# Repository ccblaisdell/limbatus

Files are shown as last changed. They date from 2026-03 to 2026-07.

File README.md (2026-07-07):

# limbatus

A 34-key wireless monoblock ergonomic keyboard derived from Dimetrodon.

## Current status
- Ships as a **34-key** layout (`thumb_keys_per_side: 2` in `ergogen/config.yaml`).
- Matrix is organized as a XIAO BLE-compatible logical `6 x 6` scan.
- `NFC1` is reserved for matrix use and must be configured as GPIO in firmware.

> The config also retains an optional **36-key** mode (`thumb_keys_per_side: 3`,
> which adds a third thumb key per side) as build infrastructure. The keyboard is
> designed, documented, and built as a 34-key; the 36-key path is kept working but
> not advertised.

## Latest PCB Images
- Top view: https://ccblaisdell.github.io/limbatus/limbatus-top.png
- Bottom view: https://ccblaisdell.github.io/limbatus/limbatus-bottom.png

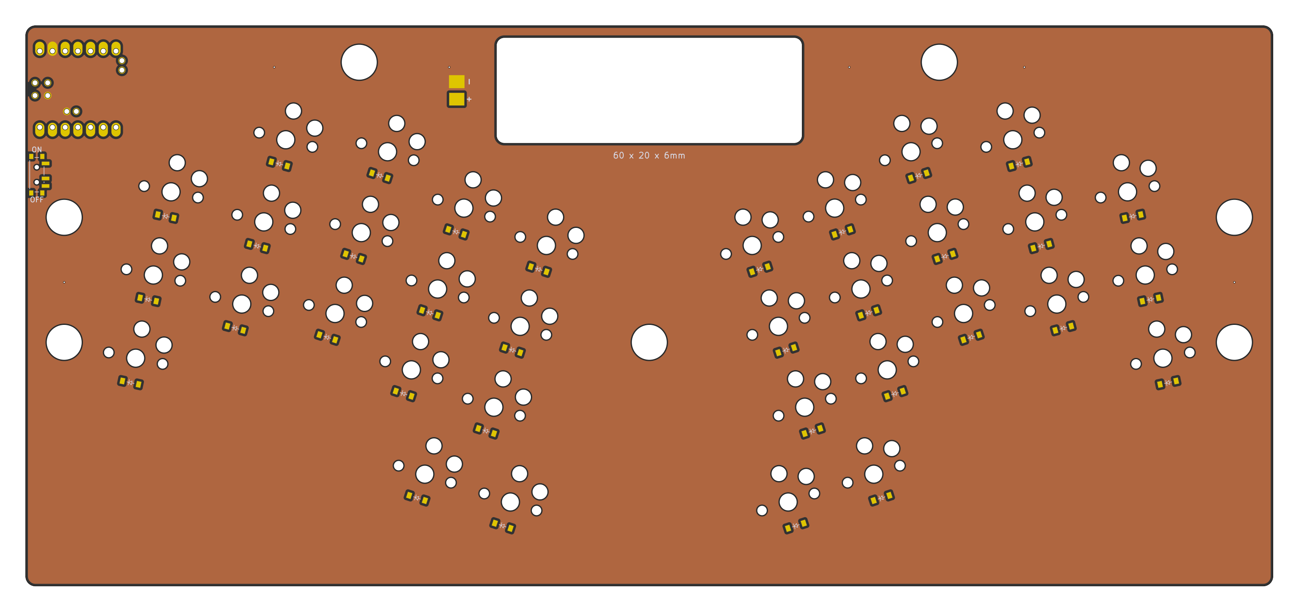
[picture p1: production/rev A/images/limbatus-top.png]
Limbatus top view

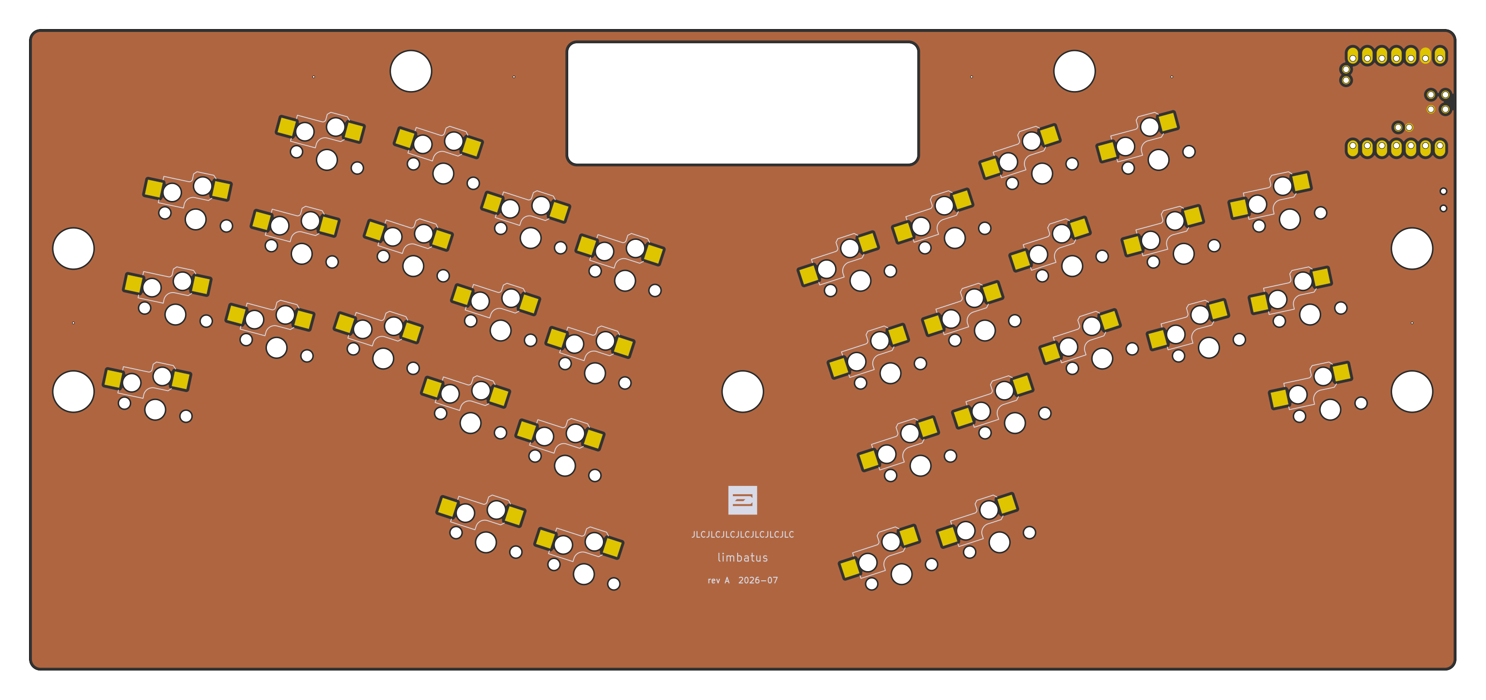
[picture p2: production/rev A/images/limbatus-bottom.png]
Limbatus bottom view


## Build
1. Install dependencies:
   - `npm install`
2. Generate artifacts:
   - `make build`

For hand-assembly (soldering and case), see [`BUILD.md`](BUILD.md). Parts list is in [`BOM.md`](BOM.md).

## Firmware
Runs [ZMK](https://zmk.dev) as a single (non-split) XIAO BLE image. The config,
keymaps, pin map, and build/flash notes live in [`config/`](config/README.md);
CI builds the `limbatus` (34-key) and `limbatus_36` (36-key) shields and uploads
`.uf2` artifacts.

Default 34-key keymap (rendered by [keymap-drawer](https://github.com/caksoylar/keymap-drawer)):

limbatus keymap

## Verify Ergogen Changes
Run this whenever you change `ergogen/config.yaml`.

1. Confirm current thumb mode value:
   - `rg -n "thumb_keys_per_side" ergogen/config.yaml`
2. Build with current mode:
   - `make build`
3. Verify generated artifacts exist:
   - `ls outlines`
   - `ls pcbs`
4. Check what changed:
   - `git status --short`
5. Validate both key-count modes before merging layout changes:
   - 34-key mode: set `thumb_keys_per_side: 2` and set both reachy `skip` fields to `true`, then run `make build`
   - 36-key mode: set `thumb_keys_per_side: 3` and set both reachy `skip` fields to `false`, then run `make build`
6. In KiCad, open the generated board and confirm:
   - no missing footprints
   - expected key count (34 or 36)
   - MCU footprint placement still valid
   - no obvious overlap/regression in thumb cluster or center bridge

## Keyboard References
- https://github.com/ceoloide/corney-island for its GitHub Actions and workflows.
- https://github.com/ccblaisdell/dimetrodon for your previous keyboard iteration.

## Notes
- Target MCU is XIAO BLE nRF52840.
- Matrix pin map target: `P0..P5` for columns, `P6..P10` plus `NFC1` for rows.
- Includes a dedicated power switch footprint.
- No JST footprint; battery uses two direct-solder SMD pads (`local/battery_pads_solder`).
- No external reset switch footprint; rely on the onboard XIAO reset button.
- The current code-generated case approach is documented in `case/README.md` and is intended to use Ergogen DXFs plus an OpenSCAD/FreeCAD export flow.

## TODO
- Add 3d models for parts where possible
- Implement the code-generated case plan in `case/README.md`
- Design a second case with embedded apple magic trackpad

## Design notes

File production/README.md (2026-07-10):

# Production artifacts

This directory holds **production bundles**: frozen snapshots of the exact
fabrication artifacts for a specific board revision — the gerbers you actually
order, together with the PCB and outlines they were generated from.

Everything else generated by Ergogen (`outlines/`, `pcbs/`) and by KiBot
(root `gerbers/`) is a **live build product** and is intentionally *not* committed
(see `.gitignore`). `ergogen/config.yaml` is the single source of truth; run
`make build` (or download the CI build artifacts) to regenerate the current
design at any time.

## Layout

```
production/
  rev <version>/                 # e.g. 2026-08-01-jlcpcb
    gerbers/
      limbatus/               # base-board gerbers
      limbatus.zip            # the zip actually uploaded to the fab
      limbatus_autorouted/    # autorouted-board gerbers (if used)
      limbatus_autorouted.zip
    limbatus.kicad_pcb        # the exact PCB the gerbers came from
    outlines/                 # matching board/case outlines
    BOM.csv                   # optional: BOM as ordered
    SOURCE.md                 # provenance: source commit, date, fab, order id
```

A bundle is **immutable** once committed. It is guaranteed internally consistent
(gerbers ⇄ PCB ⇄ outlines all from one build), which is the property root-level
live outputs cannot promise as the design evolves.

## Cutting a new production bundle

Bundles are created and committed **by hand** — nothing in CI writes here.
When you are ready to place an order:

1. Regenerate from the commit you intend to fab: `make build`, then run the
   KiBot/autoroute steps to produce `gerbers/` (or pull them from the `Build`
   workflow's `kibot-default` artifact for that commit).
2. Copy the artifacts into `production/<order-id>/`:
   - `gerbers/`            → `production/<order-id>/gerbers/`
   - `pcbs/limbatus.kicad_pcb` → `production/<order-id>/limbatus.kicad_pcb`
   - `outlines/`          → `production/<order-id>/outlines/`
3. Write `production/<order-id>/SOURCE.md` recording the source commit, date,
   fab, and order id (copy an existing bundle's `SOURCE.md` as a template).
4. Commit the bundle and tag it: `git tag fab-<order-id> && git push --tags`.

Because `outlines/`, `pcbs/`, and root `gerbers/` are gitignored, use
`git add -f production/<order-id>` — the `production/` path itself is not
ignored, so a normal `git add production/<order-id>` works too.

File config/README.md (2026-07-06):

# limbatus ZMK firmware

ZMK config for **limbatus**, a monoblock (unibody, non-split) wireless keyboard
built on a single Seeed **XIAO BLE nRF52840** driving a logical **6×6 diode
matrix**. This is the shipping **34-key** layout.

Because limbatus is unibody, each build is one firmware image (one
`board + shield` pair) — not the `_left` / `_right` split pair you'd see on a
Dimetrodon-style board. Two shields share the same board and matrix:
`limbatus` (34-key, shipping default) and `limbatus_36` (36-key, retained).

## Layout

```
build.yaml                                   GitHub Actions build matrix (both shields)
config/
  west.yml                                   ZMK + urob/zmk-helpers, both pinned
  limbatus.keymap                            34-key keymap (QWERTY / NAV / SYM / FUN)
  limbatus_36.keymap                         36-key keymap (adds the 3rd thumb/side)
  limbatus.conf                              user Kconfig (battery, sleep, logging)
  boards/shields/limbatus/
    limbatus.dtsi                            shared kscan matrix (both shields)
    limbatus.overlay                         34-key transform + chosen
    limbatus_36.overlay                      36-key transform + chosen
    limbatus.conf / limbatus_36.conf         shield requirement (NFC pins as GPIO)
    limbatus.yml / limbatus_36.yml           shield metadata
    Kconfig.shield / Kconfig.defconfig       shield selection + names
keymap_drawer.config.yaml                    keymap-drawer styling
keymap-drawer/
  limbatus.json / limbatus_36.json           physical layouts for the drawer (source)
  *.svg                                       generated keymap images (committed by CI)
.github/workflows/zmk-build.yml              firmware CI (pinned reusable workflow)
.github/workflows/draw-keymaps.yml           keymap image CI (keymap-drawer)
```

## Matrix ↔ pin mapping

The single source of truth for wiring is `ergogen/config.yaml`
(`pcbs.limbatus.footprints.xiao_ble`). This firmware mirrors it:

| Matrix | XIAO pin | ZMK reference | nRF pin |
| --- | --- | --- | --- |
| C0 | D0  | `&xiao_d 0`  | P0.02 |
| C1 | D1  | `&xiao_d 1`  | P0.03 |
| C2 | D2  | `&xiao_d 2`  | P0.28 |
| C3 | D3  | `&xiao_d 3`  | P0.29 |
| C4 | D4  | `&xiao_d 4`  | P0.04 |
| C5 | D5  | `&xiao_d 5`  | P0.05 |
| R0 | D6  | `&xiao_d 6`  | P1.11 |
| R1 | D7  | `&xiao_d 7`  | P1.12 |
| R2 | D8  | `&xiao_d 8`  | P1.13 |
| R3 | D9  | `&xiao_d 9`  | P1.14 |
| R4 | D10 | `&xiao_d 10` | P1.15 |
| R5 | NFC1 | `&gpio0 9`  | P0.09 |

Diodes run switch→row with the anode on the column side, so
`diode-direction = "col2row"`: columns are strobed outputs, rows are sampled
inputs (pulled down).

**NFC pin:** R5 lives on P0.09, an NFC antenna pin by default.
`boards/shields/limbatus/limbatus.conf` sets `CONFIG_NFCT_PINS_AS_GPIOS=y` so
P0.09/P0.10 become plain GPIO. This is written into UICR on first flash; if the
sixth row is dead, confirm this landed. (Matches the CLAUDE.md decision: "disable
NFC and use NFC1 as GPIO for the sixth matrix row.")

## Building

CI (`.github/workflows/zmk-build.yml`) builds `xiao_ble//zmk` with both the
`limbatus` and `limbatus_36` shields on every push that touches `config/**` or
`build.yaml`, and uploads a `firmware` artifact containing `limbatus.uf2` /
`limbatus_36.uf2`. Flash the one you built by double-tapping reset (via the case
tab) to enter the UF2 bootloader and dropping the `.uf2` onto the mass-storage
volume.

The board target is `xiao_ble//zmk` — the `//zmk` selects ZMK's board variant
(the SoC is omitted since nRF52840 is the only one). Plain `xiao_ble` builds the
bare Zephyr board and CI rejects it as "Missing ZMK Compat".

Local build (34-key; use `-DSHIELD=limbatus_36` for the 36-key build):

```sh
west build -s zmk/app -b 'xiao_ble//zmk' -- -DSHIELD=limbatus -DZMK_CONFIG=$(pwd)/config
```

## Keymap images

`.github/workflows/draw-keymaps.yml` renders each keymap with
[keymap-drawer](https://github.com/caksoylar/keymap-drawer) on every keymap
change and commits the SVGs into `keymap-drawer/`. limbatus is an unknown board
to keymap-drawer, so we ship the physical layout as QMK-style `info.json` files
(`keymap-drawer/limbatus.json`, `limbatus_36.json`) — a split 3×5 with 2 (or 3)
thumbs per side — which the workflow auto-detects via `json_path`.

<!-- These render once the draw-keymaps workflow has run and committed the SVGs. -->
### 34-key (`limbatus`)
limbatus keymap

### 36-key (`limbatus_36`)
limbatus_36 keymap

## Versions

ZMK and urob/zmk-helpers are pinned in `config/west.yml`; the reusable build
workflow in `.github/workflows/zmk-build.yml` is pinned to the **same** ZMK
commit. Bump them together. ZMK is currently tracking a `main` commit (there is
no release tag yet that ships the `xiao_ble` board id used here); if CI breaks
after a helper bump, re-pin to a known-good pair.

## 34-key vs 36-key

Both modes share `limbatus.dtsi` (the 6×6 kscan is identical); only the
matrix-transform and keymap differ. The 36-key build adds the third "reachy"
thumb per side at the otherwise-unused intersections **C5,R2** (left) and
**C5,R5** (right), so a 34-key board simply never scans them. Transform thumb
rows (verified against generated PCB geometry, outer→inner):

| | left thumbs | right thumbs |
| --- | --- | --- |
| 34-key | tucky `RC(0,5)`, middle `RC(1,5)` | middle `RC(4,5)`, tucky `RC(3,5)` |
| 36-key | tucky `RC(0,5)`, middle `RC(1,5)`, reachy `RC(2,5)` | reachy `RC(5,5)`, middle `RC(4,5)`, tucky `RC(3,5)` |

The 34-key `limbatus` is the advertised/shipping default; `limbatus_36` is kept
building so the option doesn't rot (mirrors the ergogen `thumb_keys_per_side`
toggle). Match the firmware you flash to the number of thumb switches you built.

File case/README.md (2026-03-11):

# Parametric Wedge Case Generator

## Summary
Build a code-generated case pipeline that uses Ergogen as the geometry source of truth and OpenSCAD as the solid-modeling layer. The repo will generate:

- board and cavity outlines as DXF from `ergogen/config.yaml`
- a two-part printable case as STL
- STEP exports via a scripted FreeCAD conversion step

The case will be a rectangular top view with a wedge side profile, split into a `top shell` and `bottom tray`. The top shell will act as a switch plate with top openings for switches/keycaps. The interior will include cavities for the XIAO, battery, and power switch, with rear openings for USB and switch access. The bottom tray will include underside cutouts for the XIAO and hotswap hardware.

## Review Notes
- Keep this aligned with repo policy: there is a dedicated power switch footprint, there is no JST battery connector, and reset access is via the onboard XIAO button unless the PCB later proves that inadequate.
- Ergogen must remain the source of truth for 2D geometry. Case inputs should be derived DXFs, not hand-maintained sketches.
- The plan needs to support both 34-key and 36-key modes. Any case-driving outlines tied to switch pattern or exterior perimeter need validation in both modes.
- The current plan is viable, but implementation should start with a minimal pipeline that proves geometry export and shell generation before adding STEP conversion and more detailed internal features.

## Implementation Changes
### Geometry source
- Extend `ergogen/config.yaml` with named case-driving outlines for:
  - outer board/case perimeter
  - switch opening pattern / plate geometry
  - diode clearance envelope if top-side diode placement requires local extra case depth or relief
  - battery cavity footprint
  - XIAO cavity footprint
  - power-switch cavity footprint
  - rear USB opening footprint
  - rear power-switch opening footprint
  - underside XIAO clearance
  - underside hotswap clearance
  - split reference geometry for top shell vs bottom tray
- Keep Ergogen as the single source of truth for all 2D placement data. No separate hand-authored cavity DXFs.

### Case generator
- Add an OpenSCAD-based case generator under a dedicated case area, with inputs pointing at generated DXFs from `outlines/`.
- Model the case as a rectangular planform extruded into a wedge profile:
  - rear height sized to clear the tallest enclosed components: XIAO and battery
  - front height tapered to near-PCB coverage
  - front overhang extends `10 mm` beyond the PCB after the taper
- Generate two solids:
  - `top_shell`: top plate + wedge exterior + internal cavity ceiling/walls + rear openings
  - `bottom_tray`: mating lower shell with underside cutouts and hardware bosses
- Top shell behavior:
  - switch-plate-style top openings sized for switch retention
  - keycap clearance windows above the switch pattern
  - local clearance or relief for top-side diodes if the final PCB keeps them on the switch side
  - internal cavities for XIAO, battery, and power switch
  - rear openings for USB access and power-switch actuation/access
- Bottom tray behavior:
  - mating lip or alignment geometry against the top shell
  - underside cutouts for XIAO protrusion and hotswap/socket clearance
  - internal support geometry that does not interfere with switches, battery, or wiring
- Join method:
  - heat-set insert bosses designed into one half
  - matching screw clearance holes in the other half
  - screw positions must avoid switch openings, battery cavity, MCU cavity, and edge openings

### Build/export pipeline
- Add a case build stage that:
  - runs Ergogen to regenerate all DXF inputs
  - runs OpenSCAD to emit STL for both halves
  - runs scripted FreeCAD conversion to emit STEP for both halves
- Default outputs:
  - STL for direct printing
  - STEP for graphical CAD import
- Keep the case artifacts reproducible outputs, not hand-edited sources.

### Interfaces and parameters
- Add a small, explicit set of case parameters for things not already in Ergogen:
  - rear case height
  - front case height / PCB-cover thickness
  - wall thickness
  - floor thickness
  - top shell thickness / plate thickness
  - cavity clearance margins per component class
  - front overhang (`10 mm` default)
  - screw size / insert size / boss diameter
- Do not infer these from KiCad. They should be repo-controlled parameters in code/config so the case stays printable and tunable.

## Implementation Order
1. Define the minimal set of Ergogen outlines needed for a first-pass shell: exterior perimeter, switch plate openings, USB opening reference, XIAO clearance, battery clearance, and power-switch clearance/access.
2. Add a case source tree with parameterized OpenSCAD that can generate `top_shell` and `bottom_tray` from those DXFs.
3. Wire a reproducible build target that emits STL artifacts.
4. Add STEP export through FreeCAD only after STL geometry is stable.
5. Expand internal clearances, bosses, and underside reliefs once the shell split and fit strategy are validated.

## Open Questions Before Full Implementation
- Whether the battery cavity should target one exact cell footprint first or support a small range through parameters.
- Whether top-side diode relief is still needed after the PCB footprint/layout is finalized.
- Whether the underside XIAO relief belongs only in the bottom tray or should also influence shell split height.

## Test Plan
- Geometry generation:
  - `make build` still succeeds and emits all required DXFs
  - case build emits both STL and STEP files for top shell and bottom tray
- Fit checks:
  - top shell encloses current XIAO, 60 mm battery footprint, and power switch with explicit clearance
  - bottom tray underside cutouts align with XIAO underside features and hotswap interference zones
  - rear openings align with XIAO USB position and power switch location
- Printability checks:
  - both halves are manifold solids
  - no trapped impossible-overhang cavities for normal FDM printing
  - heat-set bosses have sufficient surrounding material and do not break through cavity walls
- Mode compatibility:
  - case generation works for both 34-key and 36-key layouts
  - switch openings and external perimeter remain valid in both modes
- CAD interoperability:
  - STEP files open in graphical CAD software without missing bodies
  - STL and STEP shapes are visually consistent

## Assumptions and defaults
- Modeling stack: OpenSCAD source, FreeCAD used only as a conversion/export stage for STEP.
- Split strategy: top shell + bottom tray.
- Top surface role: switch-plate-style retention, not a cosmetic shell.
- Cavity/opening source: Ergogen-generated DXFs in this repo.
- Export targets: STL and STEP are both required by default.
- Front lip: extends `10 mm` beyond the PCB after taper, as requested.
- “Tall enough to cover the XIAO and battery” means rear wedge height is driven by the current tallest installed component plus configurable clearance, not hardcoded to today’s dimensions.
- A dedicated case feature is reserved for the power switch footprint and its external access.

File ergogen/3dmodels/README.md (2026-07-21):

# 3D models

STEP models used for **design-time visualization** of the PCB in KiCad's 3D
viewer. They are *not* fabrication data — gerbers, drills, and the netlist do
not reference them, so nothing here affects what gets manufactured.

## How they are wired up

`ergogen/config.yaml` sets each footprint's `*_3dmodel_filename` parameter to a
path rooted at KiCad's built-in **`${KIPRJMOD}`** variable — the directory that
holds the open `.kicad_pcb`, i.e. `pcbs/`:

```
${KIPRJMOD}/../ergogen/3dmodels/<File>.step
```

Because `${KIPRJMOD}` is resolved by KiCad automatically, **no Preferences →
Configure Paths setup is required** — open `pcbs/limbatus.kicad_pcb` and the
models load. (The ceoloide switch / diode / power-switch footprints already
support `*_3dmodel_filename`; the `local/xiao_ble` footprint was extended with
an `xiao_3dmodel_filename` parameter to do the same.)

Ergogen passes the `${KIPRJMOD}` string through verbatim into the generated
`.kicad_pcb`; there is no build/post-processing step.

Note: the frozen bundles under `production/<order-id>/` copy the `.kicad_pcb`
into their own directory, so `${KIPRJMOD}/../ergogen/3dmodels` will not resolve
there. That is intentional — those are fab records for gerber review, not 3D
previews.

## Placement note (XIAO)

`XIAO-nRF52840.step` is Seeed's official mechanical export. It is authored in a
**Y-up** frame (length along X, width along Z) and offset from the origin, so it
is not aligned to KiCad's footprint origin. The `xiao_3dmodel_xyz_rotation`
(`[90, 0, 90]`) / `_offset` (`[6.2, -1.6, 0]`) in `config.yaml` map it into
KiCad's Z-up footprint frame and were tuned and verified visually in KiCad's
footprint 3D tab. The switch, hotswap, keycap, and power-switch transforms are
the community-tuned values from the ceoloide/infused-kim footprints.

## Model sources & licenses

Each file keeps the license of its upstream source. This directory aggregates
third-party models for convenience; it does not relicense them.

| File | Part | Source |
|---|---|---|
| `XIAO-nRF52840.step` | Seeed XIAO nRF52840 (incl. BLE antenna + USB-C) | Seeed Studio official 3D model — <https://wiki.seeedstudio.com/XIAO_BLE/> |
| `Choc_V1_Switch.step` | Kailh Choc v1 switch | Joe Scotto, ScottoKeebs — <https://github.com/joe-scotto/scottokeebs> |
| `Choc_V1_Hotswap.step` | Choc v1 hotswap socket | Joe Scotto, ScottoKeebs — <https://github.com/joe-scotto/scottokeebs> |
| `Choc_V1_Keycap_MBK_White_1u.step` | MBK 1u keycap | Darryldh (Thingiverse thing:4564253); color variant by @infused-kim |
| `Diode_1N4148W.step` | 1N4148W diode (SOD-123) | SnapEDA — <https://www.snapeda.com/parts/1N4148W-13-F/Diodes%20Inc./view-part/> |
| `Switch_Power.step` | C&K PCM12SMTR slide switch | SnapEDA — <https://www.snapeda.com/parts/PCM12SMTR/C&K/view-part/> |

The choc / diode / power-switch models were vendored from the
`ceoloide/ergogen-footprints` + `infused-kim` model collections (see that
project's `3d_models/README.md` for the same attribution).

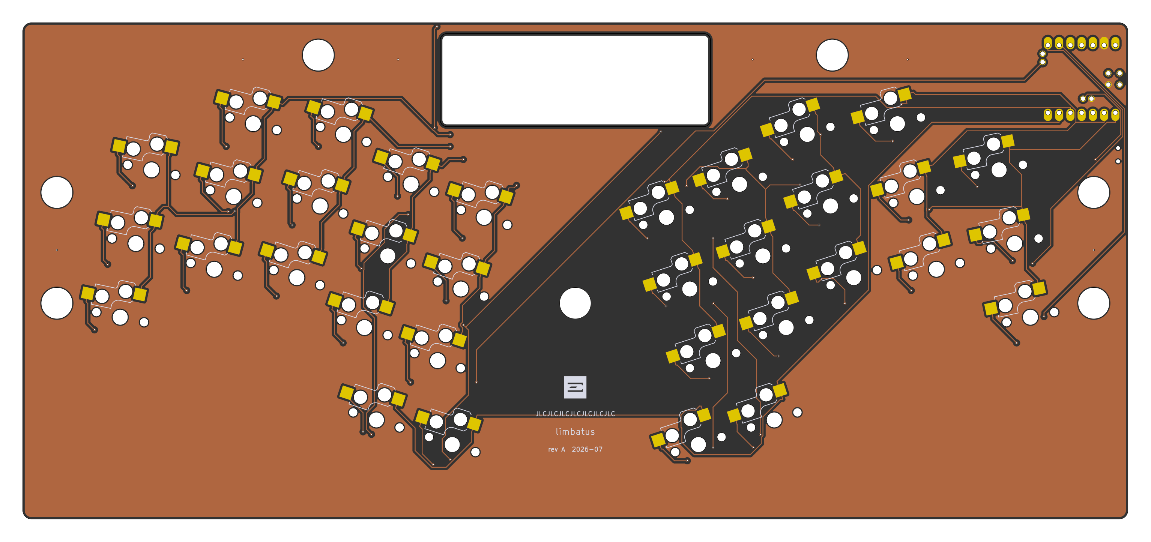
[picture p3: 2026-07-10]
production/rev A/images/limbatus_autorouted-bottom.png

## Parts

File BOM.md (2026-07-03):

# limbatus — Bill of Materials

34-key (`thumb_keys_per_side: 2`) monoblock wireless build. Quantities below are
for **one** keyboard.

> Generated from `ergogen/config.yaml`. The switches, keycaps, battery, and case
> hardware are **not** on the PCB netlist, so a KiCad-derived BOM would only list
> the XIAO, hotswap sockets, diodes, and power switch — the rest is tracked here
> by hand.

## On-PCB electronics

| Ref | Qty | Component | Package / footprint | Notes |
|-----|-----|---|---|---|
| MCU1 | 1 | Seeed Studio XIAO BLE nRF52840 | through-hole module (`local/xiao_ble`) | Wireless MCU. NFC must be disabled in firmware so `NFC1` works as the R5 row GPIO. Battery power enters via the XIAO's **BAT+/BAT−** pads (`BAT_POS`→`RAW`, `BAT_NEG`→`GND`) so the onboard charger manages the cell — these pads must be connected (see BUILD.md). |
| D1–D34 | 34 | 1N4148W switch diode | SOD-123, **SMD**, front side (`ceoloide/diode_tht_sod123`) | One per key. Cathode toward the row net. |
| — (per switch) | 34 | Kailh Choc hotswap socket | Choc v1 hotswap, SMD (`ceoloide/switch_choc_v1_v2`) | Soldered to the PCB; switches drop in. |
| PWR1 | 1 | Alps SSSS811101 slide switch | SMD side-operated (`ceoloide/power_switch_smd_side`) | On/off, in series in the battery + line (`Braw`→`RAW`). At the **west board edge, just south of the USB port** (actuator faces west, breaching the left case wall under the USB opening). Shorter than the hotswap sockets, mounted on the same (front) side. (e.g. Typeractive / LCSC) |
| BAT1 | 1 | LiPo cell, direct-solder | 2 solder pads (`local/battery_pads_solder`) | ~60 × 20 × 6 mm cell, e.g. a 602060 pouch (~600–700 mAh); footprint must stay ≤ ~82 × 23 mm (width capped ~82 mm by the pinky-top keys). **No JST connector** — leads solder directly to BAT pads (`Braw` = +, `GND` = −). **No JST connector** — leads solder directly to BAT pads (`Braw` = +, `GND` = −). The cell drops into a **PCB pocket** (full-footprint cutout) and rests on the bottom-tray floor, sitting ~1 board thickness lower; pads are on solid copper just west of the pocket (toward the XIAO/switch corner). |

## Switches & keycaps (hand-fitted, not on netlist)

| Qty | Component | Notes |
|-----|---|---|
| 34 | Kailh Choc v1 switches | Drop into the hotswap sockets. |
| 34 | Choc keycaps (1u) | Spacing is 18 × 17 mm. |

## Case hardware (mechanical)

| Qty | Component | Notes |
|-----|---|---|
| 6 | M3 heat-set threaded inserts | Pressed into the bottom-tray bosses (`MH1`–`MH6` positions). |
| 6 | M3 screws | Join the shells through the top shell into the inserts. Length TBD after a test print. |
| — | 3D-printed case | `top_shell` + `bottom_tray` (see `case/`). Front shells clip via the snap-fit lip. |

## Notes

- **Hotswap:** switches are not soldered — only the 34 Choc hotswap sockets are.
- **PCBA option:** if having JLCPCB assemble the SMD parts (sockets, diodes,
  power switch), generate a position/CPL file from KiBot — not currently emitted.
- **Diodes are SMD** (SOD-123) on the **front**; confirm orientation before reflow/hand-soldering.
- **Battery:** direct-solder pads only; observe polarity (`Braw` = +, `GND` = −). Path
  is battery + → power switch → XIAO BAT+; battery − → GND plane.
- **Ground plane:** both copper layers have a `GND` pour, so GND is a plane rather than
  routed traces (also frees the autorouter and improves the return path).
- **Insert/screw lengths** depend on the printed case and want a test print to finalize.

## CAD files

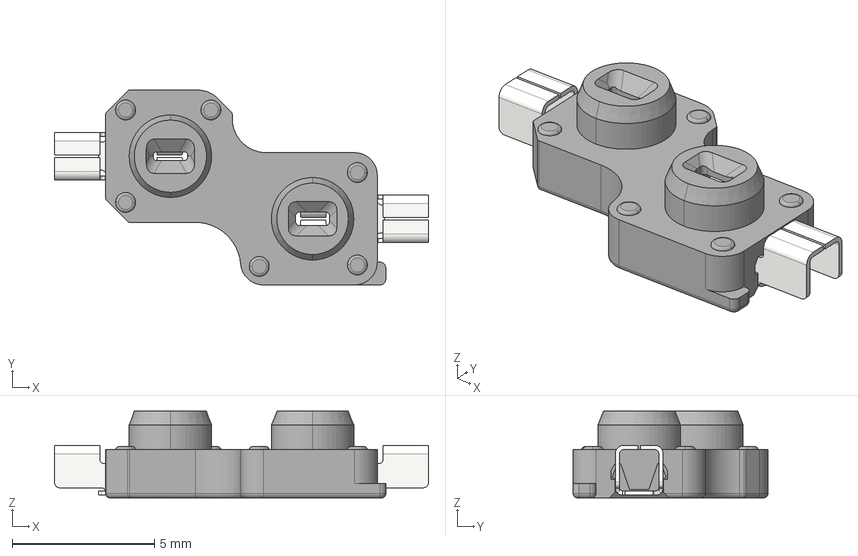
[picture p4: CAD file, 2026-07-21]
ergogen/3dmodels/Choc_V1_Hotswap.step
13.2 x 6.85 x 3.05 mm

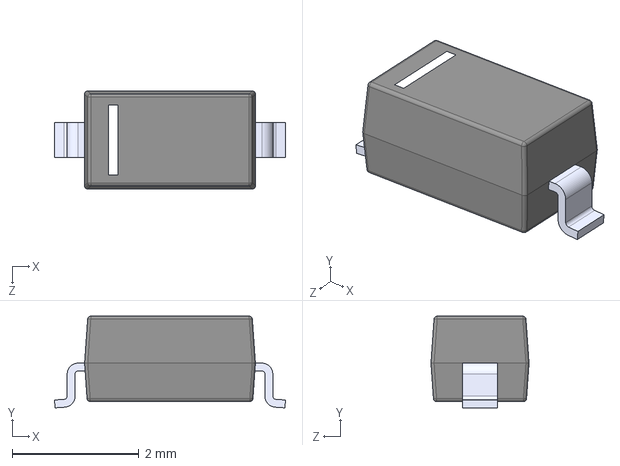
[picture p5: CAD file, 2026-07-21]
ergogen/3dmodels/Diode_1N4148W.step
3.65 x 1.45 x 1.55 mm

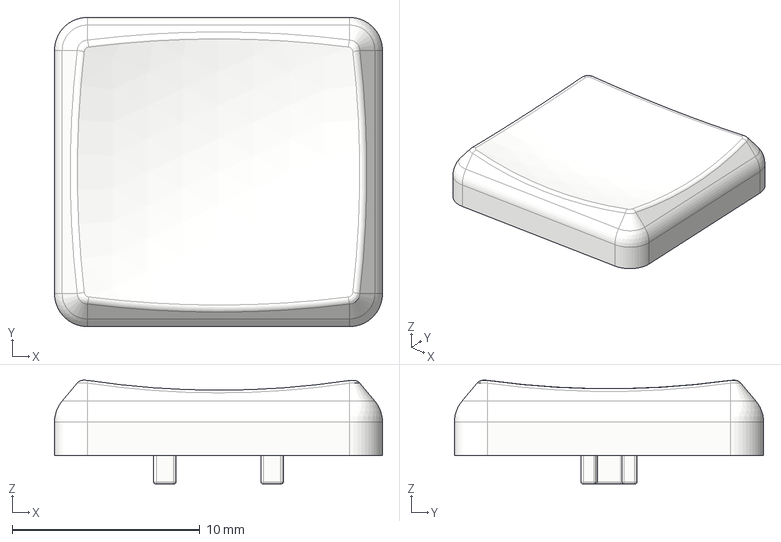
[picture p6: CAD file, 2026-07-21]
ergogen/3dmodels/Choc_V1_Keycap_MBK_White_1u.step
17.4 x 16.4 x 5.52 mm

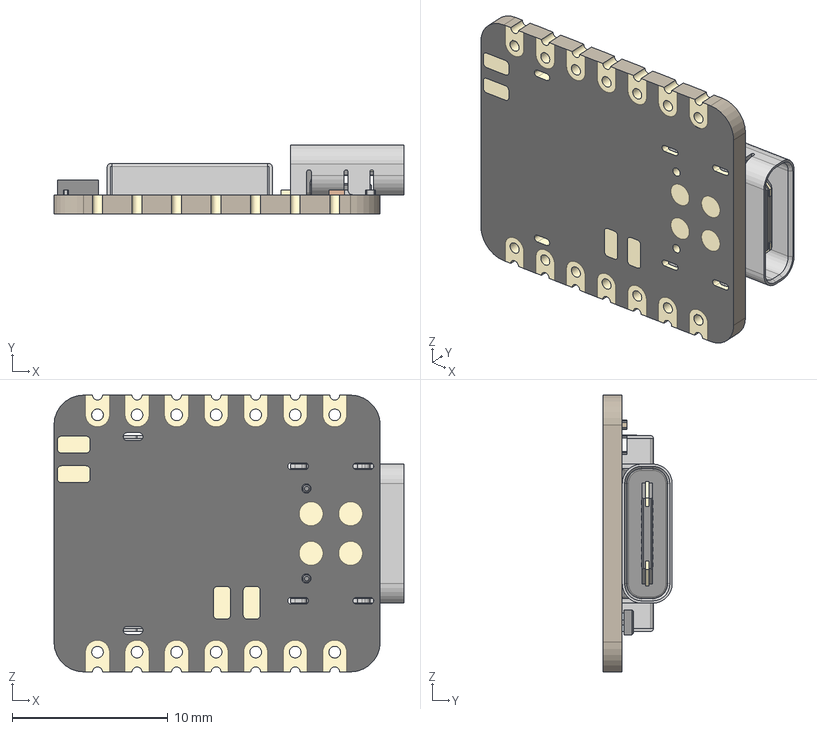
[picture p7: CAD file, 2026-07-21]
ergogen/3dmodels/XIAO-nRF52840.step
22.5 x 4.46 x 17.8 mm
BOSS-EXTRUDE14_8_
BOSS-EXTRUDE7_4_
BOSS-EXTRUDE7_3_
BOSS-EXTRUDE14_4_
BOSS-EXTRUDE14_2_
BOSS-EXTRUDE14_11_
BOSS-EXTRUDE7_7_
BOSS-EXTRUDE14_9_
BOSS-EXTRUDE14_3_
BOSS-EXTRUDE14_7_
MIRROR2
BOSS-EXTRUDE14_5_
BOSS-EXTRUDE14_12_
BOSS-EXTRUDE7_8_
BOSS-EXTRUDE7_1_
BOSS-EXTRUDE14_10_
BOSS-EXTRUDE7_9_
BOSS-EXTRUDE14_6_
BOSS-EXTRUDE14_1_
BOSS-EXTRUDE7_6_
BOSS-EXTRUDE7_2_
CUT-EXTRUDE5
BOSS-EXTRUDE7_5_
Shield
Pins
CAP x 2
ANT1
Silkscreen
CAP 3
LED
USR
2 v1

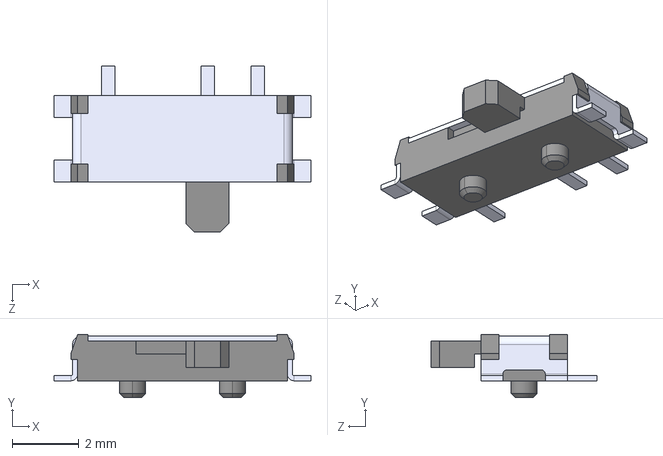
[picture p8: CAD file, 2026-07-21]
ergogen/3dmodels/Switch_Power.step
7.72 x 1.91 x 4.98 mm

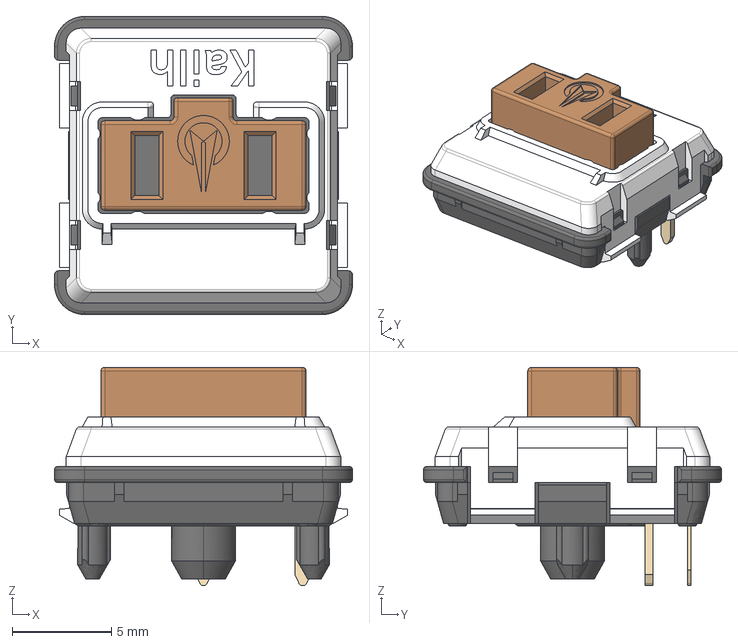
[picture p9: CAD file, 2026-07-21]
ergogen/3dmodels/Choc_V1_Switch.step
15.0 x 15.0 x 11.0 mm

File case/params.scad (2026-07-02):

// All dimensions in mm.
// Ergogen-derived component values are mirrors of ergogen/config.yaml.

// Shell thickness
wall_thickness  = 2.5;
floor_thickness = 1.5;

// PCB thickness
pcb_thickness = 1.6;

// Wall heights (rear = XIAO/battery side, front = thumb cluster side)
// Rear hides switch bodies (5.0mm) and XIAO (pcb_thickness + 4.5 = 6.1mm above PCB surface).
// Front is floor_thickness only — switches fully exposed.
rear_height  = 7.0;
front_height = 1.5;  // = floor_thickness

// Front lip overhang beyond PCB perimeter
front_overhang = 10.0;

// Shell split height (bottom tray top / top shell bottom interface)
// 1.5mm floor + ~2.5mm clearance for hotswap socket pins (~2mm below PCB)
split_height = 4.0;

// PCB retaining ledge
ledge_width  = 1.5;
ledge_height = 1.2;

// Z-axis component clearances (ergogen DXF already has XY clearance)
xiao_z_clearance    = 1.0;
battery_z_clearance = 1.0;

// Component heights (mirrors of ergogen/config.yaml)
xiao_height       = 4.5;
battery_thickness = 6.0;   // mirror of ergogen battery_thickness

// Fasteners
screw_diameter           = 3.0;
screw_head_diameter      = 5.5;
insert_diameter          = 4.5;
insert_depth             = 5.0;
boss_diameter            = insert_diameter + 2.0;
boss_height              = insert_depth + 1.0;
screw_clearance_diameter = screw_diameter + 0.4;

// Mounting bosses
// XY positions come from outlines/case_mounting_holes.dxf (single source of
// truth = ergogen). That DXF is circles of pcb_mounting_hole_diameter, which
// the case offsets to derive boss / insert / clearance diameters.
pcb_mounting_hole_diameter = 7.0;   // mirror of ergogen mounting_hole_diameter
// The tray is too shallow for an M3 insert, so the boss rises from the tray
// floor, up through the PCB clearance hole, and protrudes above the split
// plane into the (open-top) top shell, where the insert and screw live.
boss_protrusion = 3.5;              // boss height above the split plane
boss_top_z      = split_height + boss_protrusion;
boss_clearance  = 0.5;              // radial gap for the boss in the top shell

// Front snap-fit lip
// The thin wedge front (~1.5mm) is too shallow for screws, so the two shells
// clip together along the front edge instead. A continuous flexing skirt on the
// top shell drops below the split plane into the tray; a bead on the skirt's
// outer face snaps into a groove cut in the tray's inner wall. Geometry follows
// outlines/case_perimeter.dxf, masked to the front band (DXF +y <= snap_front_y).
// These values are a first pass — tune the bead/gap against a test print.
snap_front_y         = 18;    // run the snap from the front edge up to this DXF y
snap_skirt_thickness = 1.2;   // flexing skirt wall thickness
snap_skirt_depth     = 2.3;   // skirt drop below the split plane (tip stays above floor)
snap_gap             = 0.2;   // clearance between skirt and tray inner wall
snap_bead_size       = 0.4;   // bead protrusion / groove depth (interference = size - gap)
snap_bead_height     = 0.8;   // bead/groove vertical size
snap_bead_inset      = 0.7;   // bead center height above the skirt tip

$fn = 64;

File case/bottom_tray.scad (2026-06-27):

include <params.scad>
include <lib/utils.scad>
include <lib/snap.scad>

// DXF paths (relative to this file)
DXF_PERIMETER   = "../outlines/case_perimeter.dxf";
DXF_XIAO_CAVITY = "../outlines/case_xiao_cavity.dxf";
DXF_MOUNT       = "../outlines/case_mounting_holes.dxf";

// Offsets from the pcb_mounting_hole_diameter circles in the mount DXF.
BOSS_OFFSET   = (boss_diameter   - pcb_mounting_hole_diameter) / 2;  // -> boss OD
INSERT_OFFSET = (insert_diameter - pcb_mounting_hole_diameter) / 2;  // -> insert pocket

module bottom_tray() {
    difference() {
        union() {
            // Tray body: outer flat body with interior hollow and cavities.
            difference() {
                // Outer flat body
                linear_extrude(height = split_height)
                    import(DXF_PERIMETER, convexity = 4);

                // Interior hollow
                translate([0, 0, floor_thickness])
                    linear_extrude(height = split_height)
                        offset(delta = -wall_thickness)
                            import(DXF_PERIMETER, convexity = 4);

                // XIAO underside protrusion clearance
                translate([0, 0, -EPSILON])
                    linear_extrude(height = floor_thickness + EPSILON)
                        import(DXF_XIAO_CAVITY, convexity = 4);

                // TODO: hotswap socket underside clearance (needs case_hotswap_clearance.dxf
                //       from ergogen — Choc hotswap sockets protrude ~2mm below PCB)
            }

            // Mounting bosses: solid pillars from the tray floor up through the
            // PCB clearance hole, protruding above the split plane.
            linear_extrude(height = boss_top_z)
                offset(delta = BOSS_OFFSET)
                    import(DXF_MOUNT, convexity = 4);
        }

        // Heat-set insert pockets, opening upward at the boss top.
        translate([0, 0, boss_top_z - insert_depth])
            linear_extrude(height = insert_depth + EPSILON)
                offset(delta = INSERT_OFFSET)
                    import(DXF_MOUNT, convexity = 4);

        // Front snap-fit groove in the inner wall (receives the top-shell bead).
        front_snap_groove() import(DXF_PERIMETER, convexity = 4);
    }
}

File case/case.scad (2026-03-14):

include <params.scad>
use <top_shell.scad>
use <bottom_tray.scad>

// Render a single part or both in exploded view.
// Override from CLI: openscad -D 'part="top_shell"' ...
part = "both";

EXPLODE_Z = 30;

if (part == "top_shell") {
    top_shell();
} else if (part == "bottom_tray") {
    bottom_tray();
} else {
    bottom_tray();
    translate([0, 0, split_height + EXPLODE_Z])
        top_shell();
}

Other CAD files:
case/top_shell.scad

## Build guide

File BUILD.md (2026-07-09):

# limbatus — Build Guide

Hand-assembly guide for a **34-key** (`thumb_keys_per_side: 2`) monoblock wireless
build. This walks through soldering and assembly in the recommended order. Pair it
with [`BOM.md`](BOM.md) for the parts list.

> **Everything here is hand-soldered.** No reflow/PCBA step is assumed. The board
> mixes a few SMD parts (diodes, hotswap sockets, power switch) with one
> through-hole module (the XIAO) and direct-solder pads (battery). Work from the
> lowest/most-fragile parts to the tallest so nothing blocks your iron.
>
> **Heads-up on GND pads:** the ground pads — the XIAO's GND castellations and the
> battery **−** (`GND`) pad — are tied **solidly** to the board-wide ground plane
> (no thermal-relief spokes), so they sink heat fast. Give them extra dwell, plenty
> of flux, and bump the iron ~20–30 °C hotter than for signal pads; a chisel tip
> helps. (Solid GND connections keep the autorouted plane fill clean; see CLAUDE.md.)

## Tools & supplies

- Temperature-controlled soldering iron, fine conical or chisel tip
- Thin solder (0.5–0.8 mm), leaded is easiest for hand work
- Flux (paste or pen) — makes the SMD work far more forgiving
- Fine tweezers, flush cutters
- Solder wick + iso alcohol for cleanup
- Multimeter (continuity mode) for checking joints before powering on
- Optional: helping hands / PCB holder, breadboard (for the XIAO step)

## Recommended assembly order

1. [Diodes](#1-diodes-smd) — SMD, flattest parts, do them first
2. [Hotswap sockets](#2-hotswap-sockets-smd) — SMD
3. [Power switch](#3-power-switch-smd) — SMD
4. [XIAO BLE MCU](#4-xiao-ble-mcu-through-hole) — through-hole, direct solder
5. [Battery](#5-battery-direct-solder-pads) — direct-solder pads
6. [Continuity check & first power-on](#6-continuity-check--first-power-on)
7. [Firmware](#7-firmware) — flash + disable NFC
8. [Case assembly](#8-case-assembly)

---

## 1. Diodes (SMD)

> _TODO: expand._ 34× 1N4148W (SOD-123) on the **front** side. Cathode (the bar on
> the package and the silkscreen) faces the **row** net — confirm orientation
> before soldering; they're directional. Technique: tin one pad, place the diode
> with tweezers while reheating, then solder the second end.

## 2. Hotswap sockets (SMD)

> _TODO: expand._ 34× Kailh Choc v1 hotswap sockets. Switches are **not** soldered
> — only the sockets are. Tin one pad, seat the socket flat, solder, then do the
> second pad. Make sure each socket sits flush so switches seat fully.

## 3. Power switch (SMD)

> _TODO: expand._ 1× Alps SSSS811101 side-operated slide switch
> (`power_switch_smd_side`), `Braw` → `RAW`. Shorter than the hotswap sockets, same
> (front) side of the board. It sits at the **west (left) board edge, just south
> of the USB port** (immediately below the XIAO), actuator facing **west** so it
> breaches the left case wall right under the USB opening. It is
> in series in the battery **positive** line: battery + (`Braw`) → switch → `RAW` →
> XIAO BAT+ (see step 4).

## 4. XIAO BLE MCU (through-hole)

The board uses a **through-hole** XIAO footprint (`local/xiao_ble`): the 14 main
pins are plated through-holes on 2.54 mm / 0.1" pitch, so it's soldered with header
pins — the easier method for hand assembly. We are **direct-soldering** the XIAO
(not socketing it): lower profile and more rugged.

The XIAO ships with two 7-pin header strips in the box — that's all you need.

### Steps

1. **Solder the headers to the XIAO first.** Insert the two 7-pin strips up through
   the XIAO's castellated edges from the **bottom**, long pins pointing down, so the
   XIAO rests on the short stubs. Solder the castellations to the pins. (Soldering
   the XIAO first means you never have to reach past the PCB to its pads.)
2. **Seat the assembly into the PCB.** The down-pointing pins drop into the board's
   through-holes. The XIAO is rotated 90° so **USB-C must exit the LEFT board edge**
   (toward the case USB cutout on that side) — this lets the board sit on a laptop
   while plugged in without the cable fouling the screen hinge. It's easy to install
   rotated the wrong way, so dry-fit against the case first. Let it rest flat on the
   bench so it sits square.
3. **Tack one corner, check, then finish.** Solder a single corner pin, confirm the
   XIAO is flat and the USB-C lines up with the opening, then solder the remaining 13
   pins from the **underside** of the PCB.
4. **Trim flush.** Cut the pin stubs flush under the board so they don't foul the
   bottom-tray floor.

### Orientation & fit

- **USB-C** exits the **left board edge** (the XIAO is rotated 90° in the config).
  Confirm against the case USB opening before soldering.
- Soldered direct, the XIAO body rides ~1.5 mm above the PCB on the pin shoulders.
  You _can_ solder the castellations straight into the through-holes (no headers) for
  the lowest possible profile, but headers are easier to get flat and to rework —
  keep the headers.

### BAT+/BAT− carry the battery feed — connect them

The board delivers battery power **through the XIAO's own BAT+/BAT− pads** so the
onboard charger/PMIC manages the LiPo (charging over USB-C, battery run otherwise).
The path is: battery direct-solder pads (step 5) → power switch → **XIAO BAT+**
(`RAW` net), and battery − → **XIAO BAT−** (`GND`). So these two inner pads **must be
connected**, not left open.

On the physical XIAO BLE, BAT+/BAT− are on the **module underside**. Solder a short
jumper from each of the module's BAT pads to the matching board through-hole
(`BAT_POS`/`BAT_NEG`) — easiest to do **before** final seating, while you can still
reach the underside. Observe polarity; a reversed BAT connection can damage the cell
and the XIAO.

### Leave these pads unpopulated

The footprint also exposes through-holes for **SWD, RST, and NFC**. None need to be
populated:

- **SWD / RST** — debug only; reset and reflashing are handled by the onboard button +
  UF2 bootloader.
- **NFC1** — already carried through the main pin array as the 6th matrix row (R5);
  nothing extra to wire.

## 5. Battery (direct-solder pads)

> _TODO: expand._ LiPo cell, **no JST connector**. Leads solder directly to the BAT
> pads: **`Braw` = + , `GND` = −** — observe polarity. The two direct-solder pads sit
> on solid copper **just west of the pocket** (grouped toward the XIAO/switch corner).
> From there, + runs through the power switch to the XIAO BAT+ pad and − ties to the
> ground plane, so the switch cuts power to the MCU. The cell drops into the PCB
> pocket and rests on the bottom-tray floor. Tin the pads, tin the leads, join.
> Consider soldering the battery **last**, and only after the continuity check, so
> you're not working near a live cell.
>
> **Keep the protection board — cut at the connector, not the cell.** Most cells
> ship as: pouch → protection board (PCM, under Kapton tape at the wire end) →
> leads → JST plug. Snip the **leads just before the JST plug** to remove only the
> connector; the PCM stays bonded to the cell (this is what you want — it guards
> against over-discharge/over-current/short). Cut **one lead at a time** so the
> snips never bridge + and − (that would short the cell). Peek under the tape first
> to confirm a PCM is actually present; some bare cells have none. Orient the cell
> so its **wire/PCM end faces the pads** (west) for the shortest leads — the pad gap
> is sized to host the PCM there. Red = `Braw` (+), black = `GND` (−).

## 6. Continuity check & first power-on

> _TODO: expand._ Before connecting the battery, use a multimeter in continuity mode
> to spot-check for shorts (especially battery + to −, and adjacent XIAO pins). Then
> power on via USB-C first; confirm the XIAO enumerates before relying on battery.
>
> Note: both copper layers carry a **GND pour**, so every ground pad (battery −, XIAO
> GND, all switch/diode grounds) reads as continuous with each other — that's
> expected, not a short. A short is GND continuity to **`Braw`/`RAW` (battery +)**.

## 7. Firmware

> Firmware is **ZMK**, in-tree under [`config/`](config/) (see
> [`config/README.md`](config/README.md) for the full pin map and build notes).
> It builds a single unibody image — board `xiao_ble//zmk`, shield `limbatus` —
> via GitHub Actions ([`.github/workflows/zmk-build.yml`](.github/workflows/zmk-build.yml)),
> which uploads a `firmware` artifact containing `limbatus.uf2`.
>
> Flash via the UF2 bootloader (double-tap reset → drag-and-drop the `.uf2` onto
> the mass-storage volume). The reset button is reached through the case tab.
>
> **NFC is disabled in firmware** (`CONFIG_NFCT_PINS_AS_GPIOS=y`) so `NFC1`
> (P0.09) works as the R5 row GPIO. Matrix pin map: `P0..P5` = columns C0–C5,
> `P6..P10` + `NFC1` = rows R0–R5, `col2row` diode direction.

## 8. Case assembly

> _TODO: expand._ Press 6× M3 heat-set inserts into the bottom-tray bosses
> (`MH1`–`MH6`). Join shells with 6× M3 screws through the top shell into the
> inserts (length TBD after a test print). Front shells clip via the snap-fit lip.
> See [`case/README.md`](case/README.md).

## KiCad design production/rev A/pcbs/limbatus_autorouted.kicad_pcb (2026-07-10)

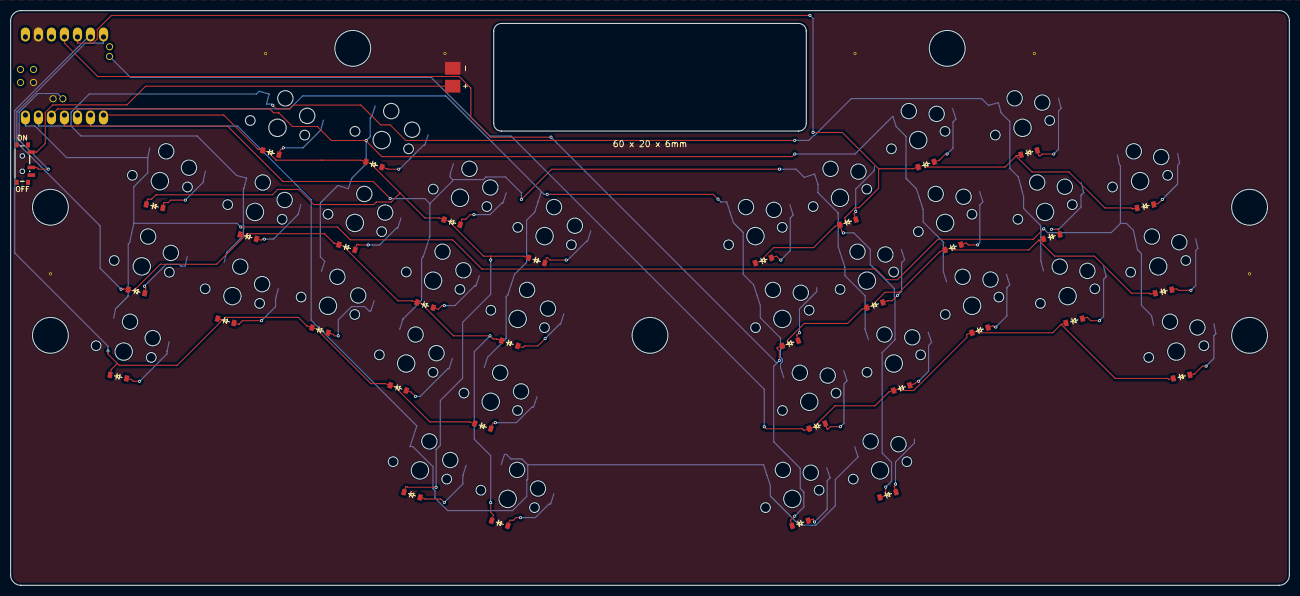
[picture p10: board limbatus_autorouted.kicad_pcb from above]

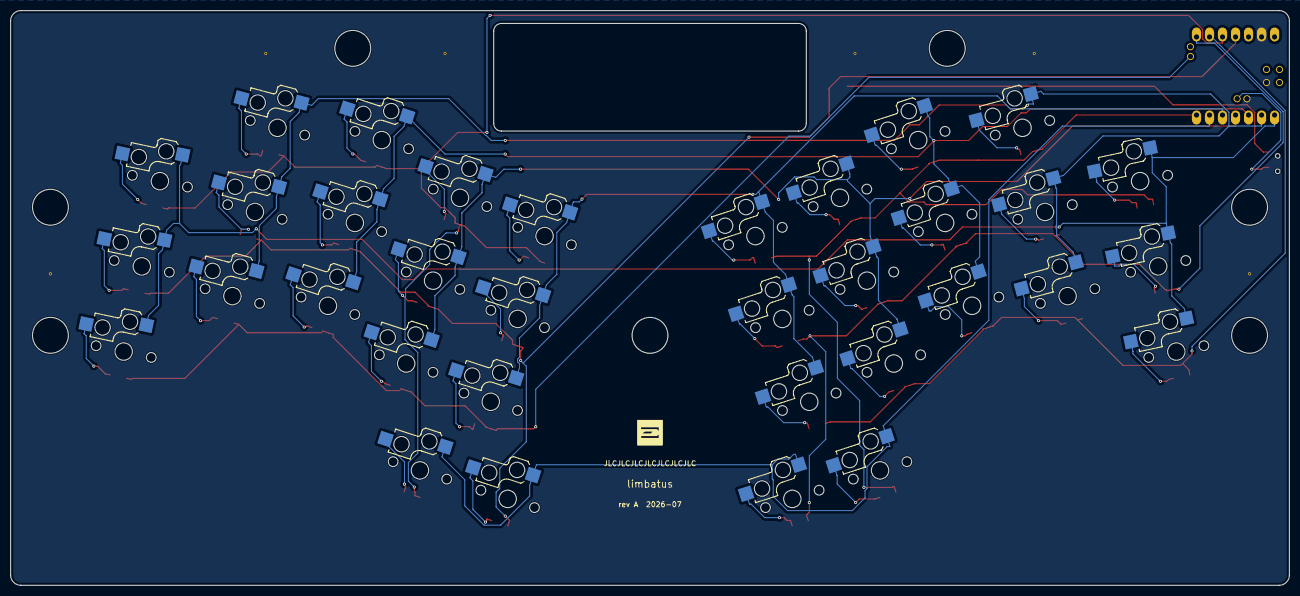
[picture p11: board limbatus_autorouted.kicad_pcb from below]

Board: 2 copper layers, 249.5 x 112.1 mm, 85 parts (35 on the bottom side), 49 nets.

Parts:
BAT1: battery_pads_solder
D1, D2, D3, D4, D5, D6, D7, D8, D9, D10, D11, D12, D13, D14, D15, D16, D17, D18, D19, D20, D21, D22, D23, D24, D25, D26, D27, D28, D29, D30, D31, D32, D33, D34: diode_tht_sod123
LOGO1: utility_ergogen_logo
MCU1: XIAO-BLE
MH1, MH2, MH3, MH4, MH5, MH6, MH7: mounting_hole_npth
PWR1: power_switch_smd_side
S1, S2, S3, S4, S5, S6, S7, S8, S9, S10, S11, S12, S13, S14, S15, S16, S17, S18, S19, S20, S21, S22, S23, S24, S25, S26, S27, S28, S29, S30, S31, S32, S33, S34: switch_choc_v1_v2
V1, V2, V3, V4, V5, V6: stitching_via

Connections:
Braw: BAT1.1, PWR1.1
C0: MCU1.1, S1.1, S2.1, S3.1, S18.1, S19.1, S20.1
C1: MCU1.2, S4.1, S5.1, S6.1, S21.1, S22.1, S23.1
C2: MCU1.3, S7.1, S8.1, S9.1, S24.1, S25.1, S26.1
C3: MCU1.4, S10.1, S11.1, S12.1, S27.1, S28.1, S29.1
C4: MCU1.5, S13.1, S14.1, S15.1, S30.1, S31.1, S32.1
C5: MCU1.6, S16.1, S17.1, S33.1, S34.1
GND: BAT1.2, MCU1.13, MCU1.17, MCU1.20, V1.1, V2.1, V3.1, V4.1, V5.1, V6.1
R0: D3.1, D6.1, D9.1, D12.1, D15.1, D16.1, MCU1.7
R1: D2.1, D5.1, D8.1, D11.1, D14.1, D17.1, MCU1.8
R2: D1.1, D4.1, D7.1, D10.1, D13.1, MCU1.9
R3: D20.1, D23.1, D26.1, D29.1, D32.1, D33.1, MCU1.10
R4: D19.1, D22.1, D25.1, D28.1, D31.1, D34.1, MCU1.11
R5: D18.1, D21.1, D24.1, D27.1, D30.1, MCU1.21
RAW: MCU1.19, PWR1.2
SW_left_matrix_inner_bottom: D13.2, S13.2
SW_left_matrix_inner_home: D14.2, S14.2
SW_left_matrix_inner_top: D15.2, S15.2
SW_left_matrix_middle_bottom: D7.2, S7.2
SW_left_matrix_middle_home: D8.2, S8.2
SW_left_matrix_middle_top: D9.2, S9.2
SW_left_matrix_pinky_bottom: D1.2, S1.2
SW_left_matrix_pinky_home: D2.2, S2.2
SW_left_matrix_pinky_top: D3.2, S3.2
SW_left_matrix_pointer_bottom: D10.2, S10.2
SW_left_matrix_pointer_home: D11.2, S11.2
SW_left_matrix_pointer_top: D12.2, S12.2
SW_left_matrix_ring_bottom: D4.2, S4.2
SW_left_matrix_ring_home: D5.2, S5.2
SW_left_matrix_ring_top: D6.2, S6.2
SW_left_thumbs_middle_cluster: D17.2, S17.2
SW_left_thumbs_tucky_cluster: D16.2, S16.2
SW_mirror_left_matrix_inner_bottom: D30.2, S30.2
SW_mirror_left_matrix_inner_home: D31.2, S31.2
SW_mirror_left_matrix_inner_top: D32.2, S32.2
SW_mirror_left_matrix_middle_bottom: D24.2, S24.2
SW_mirror_left_matrix_middle_home: D25.2, S25.2
SW_mirror_left_matrix_middle_top: D26.2, S26.2
SW_mirror_left_matrix_pinky_bottom: D18.2, S18.2
SW_mirror_left_matrix_pinky_home: D19.2, S19.2
SW_mirror_left_matrix_pinky_top: D20.2, S20.2
SW_mirror_left_matrix_pointer_bottom: D27.2, S27.2
SW_mirror_left_matrix_pointer_home: D28.2, S28.2
SW_mirror_left_matrix_pointer_top: D29.2, S29.2
SW_mirror_left_matrix_ring_bottom: D21.2, S21.2
SW_mirror_left_matrix_ring_home: D22.2, S22.2
SW_mirror_left_matrix_ring_top: D23.2, S23.2
SW_mirror_left_thumbs_middle_cluster: D34.2, S34.2
SW_mirror_left_thumbs_tucky_cluster: D33.2, S33.2

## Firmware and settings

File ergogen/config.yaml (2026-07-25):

meta:
  engine: 4.1.0

units:
  kx: cx
  ky: cy

  $default_width: cx
  $default_height: cy

  cpx: 1 + kx / 2
  cpy: 1 + ky / 2

  # 2 or 3 thumb keys per side.
  thumb_keys_per_side: 2

  # Negative values rotate each half inward (mirrored on the right).
  inward_rotation: -12

  total_matrix_splay: 6
  half_separation: 105

  board_padding_top: 10
  board_padding_horizontal: 10
  board_padding_bottom: 0

  xiao_length: 21
  xiao_width: 17.5
  # USB exits the LEFT board edge (XIAO rotated 90deg, see points.mcu_xiao).
  # 0 keeps the connector flush with the left edge so the plug can breach the
  # case wall via case_usb_opening -- the pad-free USB end clears the edge fine,
  # exactly as the rear edge did before the rotation.
  xiao_left_clearance: 0
  # After the 90deg rotation the rear board edge hosts a castellated pad row
  # (previously the pad-free short end faced it). Inset the MCU from the rear
  # edge so those pads keep >=0.2mm copper-to-edge (KiBot DRC); 2mm yields
  # ~1.75mm. Knob kept symmetric with power_switch_top_clearance.
  #
  # Bumped 2 -> 4 (2026-07-09): moves the whole NW cluster (XIAO + the
  # power switch and USB opening derived from it) ~2mm SOUTH, opening a
  # routing channel along the north edge above the MCU castellation fanout
  # -- the congested spot that leaves the MCU-corner GND pour fragmented on
  # the autorouted preview. The power switch stays clear of MH2 (~0.9mm pad
  # gap; boss keepout still met). Pads now sit ~3.75mm off the rear edge.
  xiao_top_clearance: 4

  # Power switch is WEST-facing (actuator points out the left board edge) and
  # sits just SOUTH of the USB port -- i.e. immediately below the XIAO in the
  # left margin -- so the slide actuator breaches the west case wall through
  # case_power_switch_opening, right under the USB opening. The XIAO body spans
  # the whole west edge down to xiao_width/2 below its center, so "just south of
  # the USB" is the first clear west-edge spot: just below the XIAO south edge.
  # power_switch_south_gap = XIAO south edge -> switch north edge. Kept at 5mm
  # (not hard up against the XIAO) so a soldering iron can reach the switch's
  # north pads without fouling the adjacent MCU / its castellated pad row.
  power_switch_south_gap: 5.0
  power_switch_width: 6.7
  power_switch_length: 2.6
  # Inset the switch from the WEST board edge so its mounting-tab pads keep
  # >=0.2mm copper-to-edge clearance (KiBot DRC threshold). Measured to the
  # switch body's west edge; the tabs overhang ~0.325mm past it, so 1.0 yields
  # ~0.675mm pad-to-edge.
  power_switch_west_clearance: 1.0

  # Battery: 60 x 20 x 6mm LiPo cell (W x L x thickness), e.g. a 602060 pouch
  # (~600-700mAh). Sits in the top-center pocket with generous room for a
  # plate-level case wall between the cell and the neighbouring top-row switches.
  # The tight axis (20mm, battery_length) stays well under the ~23mm pocket
  # limit set by the pinky/ring top keys; the 60mm axis has slack (pocket fits
  # up to ~82mm wide). Set these to the actual cell's dimensions before ordering.
  battery_width: 60
  battery_length: 20
  # Thickness grows into case depth, not key clearance (the cell sits under a
  # solid lid, clear of the keys). When the battery compartment is actually
  # modelled, confirm the case rear height hosts 6mm + battery_z_clearance.
  battery_thickness: 6.0
  # Distance from the board top edge to the cell. Set >= wall_thickness (2.5)
  # so the drop-in pocket starts at/inside the case wall and leaves a solid
  # north board strip rather than undercutting the wall.
  battery_top_clearance: 3

  # Drop-in battery pocket.
  # The cutout is the FULL cell footprint plus a small clearance, so the cell
  # drops THROUGH the PCB and rests on the bottom-tray floor ~1 board thickness
  # lower (a bit more height clearance, and the cell can be a touch taller).
  # The pocket is centered on the battery; the solder pads sit on solid copper
  # just west of it (battery_pad_gap). Pocket and pads both track
  # battery_width/length, so swapping to a different cell size needs no other
  # edits. battery_pocket_clearance = gap between the cell and the pocket walls.
  battery_pocket_clearance: 0.5
  # Gap between the pocket's west edge and the solder pads. Wide enough to host
  # the cell's protection board (PCM) + short leads when the JST connector is
  # snipped off: orient the cell so its wire/PCM end faces WEST (toward these
  # pads). 8mm keeps the pads ~6mm clear of the nearest keycap (ample room in
  # the rear margin). See BUILD.md step 5.
  battery_pad_gap: 8

  case_switch_opening: 13.8
  case_component_clearance: 1
  case_usb_opening_width: 10
  case_usb_opening_depth: 4
  case_power_switch_opening_width: 8.5
  case_power_switch_opening_depth: 4
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

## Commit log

2026-03-02 Fix skip option error
    [config.yaml]
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2026-06-10 Run KiBot with DRC-enabled config in CI
    The default kibot config has preflight DRC disabled, so the workflow
    silently skipped all the filters and clearance checks that boards.kibot.yaml
    already defines. Switch both KiBot invocations (initial generation and
    post-autoroute) to the boards config, which imports the same outputs and
    adds DRC + JLCPCB-aware filters.
2026-06-10 Install OpenSCAD in CI so make build can render case STLs
    The case target was added to `make build` in 79eede8 but the ubuntu-latest
    runners don't have openscad, so every CI job has been failing on main since.
    Install it before `make build` and assert the STL outputs in the verify steps.
2026-06-24 Switch to 34-key mode (2 thumb keys per side)
    Set thumb_keys_per_side to 2 and skip the optional 3rd (reachy) thumb
    key on the mirrored left_thumbs zone, dropping the layout from 36 to
    34 keys. Verified via make build: generated PCB now has 34 switch
    footprints.
    [config.yaml]
2026-06-25 Fix KiBot DRC copper-edge-clearance failures near board top edge
    The CI KiBot DRC job failed with 10 copper_edge_clearance errors:
    - 8 were the XIAO footprint's own pads sitting 0-0.2mm from Edge.Cuts
    slots that ImStuBTW/xiao-ble stamps onto the board (an in-board /
    castellated mount style). limbatus top-mounts the XIAO inside a case
    cavity (case/README.md), so those slots are unwanted. Fork the
    footprint to local/xiao_ble with the Edge.Cuts block removed.
    - 2 were the power switch pads flush with the top board edge. Add a
    power_switch_top_clearance knob (0.5mm) to inset it; pads now clear
    the edge by ~0.275mm.
    KiBot's DRC filter accepts copper-edge clearance >=0.2mm, so compon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
    [config.yaml]
2026-06-25 Shift thumb cluster ~half a key toward board center
    Offset the thumb cluster anchor by kx/2 so the thumb keys are no longer
    column-aligned with the matrix keys directly above them. Mirrors
    correctly: left thumbs move +x, right thumbs -x, both toward center.
    [config.yaml]
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2026-06-27 Add case mounting holes and bottom-tray bosses
    Ergogen: add 6 through-PCB mounting holes (3 mirrored pairs) in the
    rear/side margins, clear of all keys, diodes, MCU, battery and power
    switch. A new `mounting` zone declares the left-side holes; the global
    mirror creates the right side. Emits ceoloide/mounting_hole_npth
    footprints (7mm, clears the boss) plus a case_mounting_holes outline so
    ergogen stays the single source of truth for the XY positions. DRC clean
    in both 34- and 36-key modes.
    Case: implement the heat-set-insert bosses (bottom_tray TODO). Bosses
    rise from the tray floor up through the PCB clearance hole and protrude
    above the split plane into the open-top top shell, where the i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
    [bottom_tray.scad, params.scad, top_shell.scad]
2026-06-27 Add front snap-fit lip to the case
    The thin wedge front (~1.5mm) can't host screws, so the two shells clip
    together along the front edge. New lib/snap.scad adds a continuous
    flexing skirt on the top shell that drops below the split plane into the
    tray; a bead on the skirt's outer face snaps into a groove cut in the
    tray's inner wall. Geometry follows case_perimeter.dxf, masked to the
    front band (DXF +y <= snap_front_y) so it stays clear of the rear bosses.
    Bead/gap/skirt dimensions are a first pass and need tuning against a test
    print.
    [bottom_tray.scad, params.scad, top_shell.scad]
2026-06-29 Enlarge battery to 80mm and add a PCB rest cutout
    Bump battery_width 60 -> 80mm (body now spans x[-40,+40]); the solder
    pads follow east to x=+35 via the existing offset, leaving room for a
    larger cell. Add a through-PCB cutout under the battery body so the cell
    sits ~1 board thickness lower for extra height clearance. The cutout is
    west-biased so the east solder pads stay on solid copper, and it is
    subtracted from the PCB board outline only (the case perimeter stays
    solid so the battery rests on the tray). DRC clean in both key modes.
    [config.yaml]
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2026-06-29 Revert battery to a top-center-fitting size; fix pad-over-cutout
    The 95x25 cell overspills the top-center pocket: at 95mm wide it
    overlaps the staggered top keys (S9/S26 keycaps reach y=-74), and 25mm
    of length pushes into them (2 DRC errors). The pocket fits ~<=82 x <=23.
    Also restore battery_cutout_east_inset (0 -> 17): at 0 the cutout
    swallowed the solder pads, leaving them floating over the hole (a silent
    defect DRC misses).
    Set a fitting placeholder of 80x20, keep the 4.0mm thickness, and mirror
    that thickness into the case. Note left in config to set exact cell dims
    before ordering. DRC clean; pads back on solid copper.
    [params.scad]
2026-06-29 Center battery pocket; place pads east of it, auto-scaling
    The battery cell is centered in the top section; make the pocket
    (cutout) centered on it too (was west-biased) with a uniform inset.
    Position the solder pads just east of the pocket via
    battery_width/2 - battery_cutout_inset + battery_pad_gap, so the pocket
    and pads both track battery_width automatically when the cell size
    changes. Replaces battery_cutout_east_inset with battery_pad_gap.
    DRC clean; pads on solid copper ~2.5mm east of the pocket.
    [config.yaml]
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2026-06-29 Round the battery pocket's inside corners (1.5mm)
    Add corner: 1.5 to the battery cutout so its inside corners are slightly
    rounded — eases the cell drop-in (LiPo pouches have rounded corners) and
    avoids sharp internal stress risers. DRC clean.
    [config.yaml]
2026-06-30 Add silkscreen label with battery size next to the pocket
    Place a ceoloide/utility_text footprint just south of the drop-in
    battery pocket reading "80 x 20 x 4mm", so the correct cell size is
    obvious during assembly. Centered on solid copper, clear of the cutout
    and the east solder pads.
    [config.yaml]
2026-06-30 Add a center-line case-mounting hole between the two halves
    Adds a seventh mount point on the x=0 center line (ergogen y=55), in the
    open pocket south of the battery cavity, to tie the two shell halves
    together in the middle. asym:source keeps the x=0 global mirror from
    stamping a coincident duplicate. Boss, heat-set insert pocket, top-shell
    clearance, and PCB npth all derive from the shared case_mounting_holes
    outline, so no case/ changes are needed. Validated in 34- and 36-key modes.
    [config.yaml]
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2026-07-01 Rotate the XIAO so USB exits the left board edge
    Rotate the MCU 90deg CCW so the USB-C connector faces the left edge
    instead of the rear, letting the board sit on a laptop and be used while
    plugged in without the cable fouling the screen hinge.
    Rotate the mcu_xiao point (not just the footprint) so the case cavity and
    USB-opening outlines, which both reference it, stay in sync. Retune
    clearances for the new orientation:
    - xiao_left_clearance 4->0: the USB end sits flush with the left edge so
    the plug breaches the case wall (the pad-free end clears the edge fine,
    as the rear end did before).
    - xiao_top_clearance 0->2: the rotation swings a castellated pad row onto
    the rear edge; the ins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
    [config.yaml]
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2026-07-01 Fix power routing: wire XIAO BAT+, cluster power parts, add GND pours
    The battery→XIAO positive rail was never completed and the power parts
    sat in three far corners, so autorouting the power nets across the dense
    matrix failed. Three fixes, no key-switch positions changed:
    - Wire the XIAO's battery input into the power net (BAT_POS: RAW,
    BAT_NEG: GND). Previously RAW dead-ended at the switch and BAT_POS was
    an isolated island, so the board delivered no power to the MCU. Now
    battery+ → Braw → switch → RAW → XIAO BAT+ closes the loop.
    - Cluster the power parts in the top-left margin: move the power switch
    beside the XIAO (new power_switch_gap_from_xiao) and flip the battery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
    [config.yaml]
2026-07-02 Resize battery to 70x23x6mm; make placement length-robust
    Swap the 80x20x4 placeholder for a 70x23x6mm cell. Width stays well under the
    ~82mm cap set by the pinky-top keys and keeps ~3.8mm to the nearest switch
    opening (room for a plate-level case wall between the cell and the top-row
    switches); the extra capacity is taken in thickness (6mm), which grows into
    case depth rather than key clearance since the cell sits under a solid lid.
    Also fix the battery anchor so its rear edge sits battery_top_clearance
    below the board rear edge for any battery_length (shift.y = -clearance -
    length/2). The old formula only yielded the intended 3mm at length 20.
    - ergogen/config.yaml: battery_width/length/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
    [params.scad]
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2026-07-02 Widen battery pad gap to 8mm for PCM; document keeping it in BUILD
    When the JST connector is snipped off, the cell's protection board (PCM)
    stays attached at the wire end. Orient that end toward the west solder pads
    and give it room: battery_pad_gap 4 -> 8mm (pads still ~6mm from the nearest
    keycap, ample rear-margin space).
    BUILD.md step 5: note to cut at the connector (not the cell) to keep the PCM,
    cut one lead at a time to avoid shorting, confirm a PCM is present, and face
    the wire/PCM end toward the pads.
    [config.yaml]
2026-07-03 Move power switch to west-facing, just south of the USB port
    Reposition the power switch from the top margin (east of the XIAO,
    actuator facing north) to the west board edge, immediately below the
    XIAO's south edge -- i.e. just south of the west-facing USB port. The
    switch point now rotates 90deg like the XIAO, so the footprint (with its
    own adjust.rotate 90) lands at 180deg: actuator out the west edge, tab/
    signal pads facing inland. The wall opening is pushed the west-clearance
    amount further west so it reaches the board edge and breaches the left
    case wall under the USB opening, matching case_usb_opening.
    Replaces power_switch_gap_from_xiao/power_switch_top_clearance with
    power_switch_so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
    [config.yaml]
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2026-07-04 Add ergogen logo silkscreen; lengthen JLC order-number placeholder
    Reference the Dimetrodon config (ceoloide utility_ergogen_logo +
    utility_text). Add the 5x5mm ergogen logo on the back silkscreen at
    board center (0,6), just north of the JLC marker -- Dimetrodon tucks it
    below the MCU, but here that spot is the west-edge power switch, so it
    goes in the same clear central gap.
    Also lengthen the JLC placeholder from 4x "JLC" (12 chars) to Dimetrodon
    7x "JLC" (21 chars): JLC scales the substituted order number into the
    placeholder box, so a longer string avoids clipping a full order number.
    Both silkscreen-only (no copper/nets), so routing is unaffected.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
    [config.yaml]
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2026-07-04 Record reset case-tab plan and RF changes in decision log
    Reset stays on the onboard XIAO button, actuated via a Forager-style
    flexible case tab (no PCB reset switch or pads). Documents the two PCB
    constraints this imposes (XIAO mounting face vs. tab shell; crowded
    west/USB corner) plus the new antenna-keepout and GND-stitching
    decisions.
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2026-07-06 Resync outlines/pcbs to config; define gerbers as production snapshots
    main went red because outlines/pcbs committed in 00dc192 were regenerated
    from an older config and never refreshed after the power-switch reposition,
    GND stitching vias, and logo/silk changes landed. The Reproducibility job
    correctly caught the drift.
    Fix and policy:
    - Regenerate outlines/pcbs from the current config so they match again and
    the Reproducibility gate passes. These artifacts track current design and
    must be committed alongside any config change (the gate enforces this).
    - Define gerbers/ as PRODUCTION snapshots, decoupled from live outputs: only
    refreshed and committed when placing a physical fab orde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
    [case_power_switch_cavity.dxf, case_power_switch_opening.dxf, debug.dxf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]
2026-07-07 Commit only production artifacts; stop committing live build outputs
    Reframe what lives in git: ergogen/config.yaml is the source of truth, and the
    only committed fabrication artifacts are frozen production bundles — never the
    live, regenerable outputs.
    - Gitignore and untrack the live build products: root outlines/, pcbs/, and
    gerbers/. Regenerate them with `make build` or pull the Build workflow's
    artifacts. This removes the whole class of "committed outputs drift from
    config" failures (stale artifacts, the daily date-stamp churn) at the root.
    - Add production/ for immutable per-order bundles: gerbers + the matching
    limbatus.kicad_pcb + outlines + SOURCE.md provenance, tagged fa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
    [board.dxf, case_battery_cavity.dxf, case_mounting_holes.dxf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]
2026-07-08 Cap autoroute passes and add a hard timeout in CI
    The autoroute step was running 25+ minutes on some CI runs. Freerouting
    v2.x headless (--gui.enabled=false) ignores the legacy `-mp` flag
    (freerouting#376), so a route that stalled at a couple of unrouted nets
    kept iterating (observed 807 passes) with no ceiling.
    - Use the dotted `--router.max_passes` settings override, which the v2
    router actually honors, so a struggling route stops after N passes and
    still writes a .ses.
    - Wrap the run in a `timeout` backstop (freerouting has no built-in job
    timeout) so the step fails fast instead of grinding for 25+ minutes if
    the cap is ever ignored too.
    - Expose max_passes and timeout as action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
2026-07-08 Move XIAO antenna keepout to the real antenna end (opposite USB)
    The XIAO nRF52840's onboard meander antenna is at the short end OPPOSITE
    the USB-C connector (verified from Seeed's official front-pinout image),
    not the USB end as the config comment assumed. With USB flush against the
    west board edge, the antenna is the EAST end of the module (~x=-103.8).
    The GND-pour keepout was placed over the USB/west end (x=-126..-117.5),
    which both left the real antenna under full ground plane (detuning BLE)
    and punched a needless F&B pour void into the congested USB corner where
    autoroute leaves nets unrouted. Relocate it to the antenna/east end
    (x=-110.76..-101.76): fixes the RF detuning and clears an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
    [limbatus.kicad_pcb]
2026-07-08 Shrink antenna keepout to the pad-free tip to fix routability
    Moving the keepout to the east/antenna end (prior commit) cut the GND
    plane out from under the XIAO pad fanout: after the 90deg rotation the
    pad rows span x -121.9..-106.6 and the wide keepout reached to -110.76,
    ~4mm into them. That orphaned GND connections and roughly doubled
    autoroute time / unrouted nets.
    Narrow the zone to the module's pad-free antenna tip and the open board
    just east of it (x -106..-100). Controlled local repro (freerouting
    2.2.4, -mp 10, only the keepout varying): wide-east = 5 unrouted / 82s,
    tip-only = 2 unrouted / 39s (matches the old west placement and nearly
    matches no keepout at all), while still cle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
    [limbatus.kicad_pcb]
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2026-07-08 Add battery-cutout edge keepout to satisfy 0.5mm board edge clearance
    Freerouting routed an R-row track/arc only 0.24mm from the internal
    battery cutout, failing KiCad's 0.5mm board-edge-clearance rule -- that
    rule is not exported into the Specctra DSN, so the autorouter only kept
    its small default off the cutout. Add a keepout ring 0.65mm around the
    cutout that forbids tracks and vias (copperpour still allowed, so the GND
    plane fills through unchanged). Freerouting honors DSN keepouts, so a
    re-route will hold routed copper clear of the cutout edge.
    [config.yaml]
2026-07-08 Fix unrouted R5: replace antenna keepout with a GND-pour notch
    The XIAO antenna GND exclusion was a utility_keepout_zone. KiCad exports
    every rule-area keepout to the Specctra DSN as a plain (keepout) that
    freerouting treats as FULLY blocking -- its copperpour_allowed:false /
    tracks_allowed:true flags are dropped on export. That zone overlapped the
    NFC1 pad (matrix row R5, MCU1 pad 21, at the antenna tip) and R5's B.Cu
    escape corridor, so freerouting could never route R5 out of the XIAO:
    a permanent unconnected "MCU1 pad 21 [R5] -> D30", independent of
    clearance, via size, or pass count.
    Cut the same region out of the gnd_pour_front / gnd_pour_back polygons
    instead: it removes the copper (i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
    [config.yaml]
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2026-07-09 CI: run the freerouting pipeline on KiCad 9 to reach 0 unrouted
    Freerouting is deterministic per-environment but its unrouted-net count
    varies with the input DSN. KiCad 9 exports a richer Specctra DSN (finer
    pad/keepout geometry; ~1560 vs ~960 lines) than KiCad 8, and freerouting
    completes the dense 2-layer matrix on it with 0 unrouted nets -- whereas
    the KiCad 8 DSN gets stuck on the center column crossings (locally C1; in
    CI's Linux env C1/C2/R4), which no clearance / pass / optimization-strategy
    tuning fixed. Switch export-dsn, import-ses, and kibot from the kicad8_auto
    image to kicad9_auto so the whole DSN/SES/DRC pipeline runs on one version.
    Verified locally with kicad-cli 9 + freerou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
2026-07-09 Solid GND fill + drop antenna void: clean autoroute DRC
    Two changes, per design decision:
    1. Remove the antenna GND exclusion. The pours now fill SOLID under the
    XIAO's onboard antenna (dropping the notch that replaced the old
    keepout). The antenna already sits ~21mm inland -- a compromised RF spot
    the small void barely helped -- and a continuous plane is simpler and
    does not fragment into isolated pour islands. Routing is unaffected (the
    plane, unlike the old keepout, does not block the autorouter): full
    route still completes with 0 unrouted nets.
    2. Harden the GND fill so the autorouted preview reports 0 unconnected
    items regardless of how a given (non-deterministic,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
    [config.yaml]
2026-07-09 GND pours: back to solid fill (drop crosshatch)
    Revert the cosmetic hatch fill. Solid copper connects GND pads/vias and
    ties the front/back planes far more robustly than a thin crosshatch grid
    (which fragments around every trace and pad clearance), and a solid ground
    is better for the 2.4GHz BLE return paths. No routing impact: fill mode is
    not exported to the Specctra DSN (byte-identical), so the autoroute still
    completes with 0 unrouted nets; local DRC is 0 unconnected, 0 violations.
    Note: this only affects the GND-fill connectivity robustness, not the
    cross-runner routing flicker (C1/C2), which is inherent to 2 layers.
    [config.yaml]
2026-07-10 Stitching vias: drop the two center-corridor (x=0) vias
    The autorouted-preview GND pours fragment where signal tracks box off a
    region of a pour. The row traces that cross the center corridor carve an
    E-W strip out of the F.Cu pour, and the two x=0 stitching vias (V1/V2)
    sit inside that strip -- pinning it as a floating island that
    `remove_islands: always` can no longer drop, which surfaces as a
    "Zone GND on F.Cu unconnected" DRC error on the autorouted board.
    Confirmed on the actual failing CI board (run 29029354355): deleting the
    two center vias takes its GND-zone-unconnected count 2 -> 1 (the F<->F
    error disappears once remove_islands can clean up the now-anchorless
    strip). No regression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
    [config.yaml]
2026-07-10 NW corner: move XIAO cluster ~2mm south (xiao_top_clearance 2->4)
    Shifts the whole northwest cluster (XIAO + the power switch and USB
    opening derived from it) ~2mm south, opening a routing channel along the
    north board edge above the MCU castellation fanout. That fanout is the
    congested spot that leaves the MCU-corner GND pour fragmented on the
    autorouted preview (the remaining "Zone GND unconnected" DRC error after
    the center-via drop).
    Geometry checks: XIAO north pads now ~3.36mm off the rear edge (was
    ~1.34mm); power switch ends ~0.86mm from MH2 (0 source-board DRC
    violations); both 34-key and 36-key modes build clean.
    Note: on local freerouting runs this shows 1 signal net unrouted (th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
    [config.yaml]
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2026-07-21 Add 3D models to PCB footprints for KiCad visualization
    Wire STEP models into the switch, hotswap socket, keycap, diode, power
    switch, and XIAO footprints so the generated PCB renders in KiCad's 3D
    viewer (design-time only; not fabrication data).
    - Commit models under ergogen/3dmodels/ and reference them from
    config.yaml via KiCad's built-in ${KIPRJMOD} path, so they resolve
    with zero "Configure Paths" setup.
    - ceoloide switch/diode/power-switch footprints already expose
    *_3dmodel_filename params; set them plus the community-tuned
    offset/rotation values (footprint side B).
    - Extend local/xiao_ble.js with an xiao_3dmodel_filename param (+offset/
    rotation/scale) and emit a (model ..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
    [Choc_V1_Hotswap.step, Choc_V1_Keycap_MBK_White_1u.step, Choc_V1_Switch.step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]
2026-07-21 Use KiCad-verified XIAO 3D model transform
    Replace the analytical estimate for the XIAO nRF52840 model placement with
    values tuned and confirmed in KiCad's footprint 3D viewer:
    offset [6.2, -1.6, 0], rotation [90, 0, 90]. Update the README/CLAUDE.md
    notes accordingly.
    [config.yaml]
2026-07-22 case: add bottom-tray underside relief outlines (hotswap + switch holes)
    Adds parametric Ergogen outlines for the components that protrude BELOW the
    PCB, so the bottom tray can be cut in Onshape from a derived DXF (per the
    case/README "underside hotswap clearance" plan) rather than a hand sketch:
    - case_hotswap_clearance: one rectangle per key covering the Kailh Choc
    hotswap socket body + pin holes (B.Cu, 4.85mm north of key center).
    - case_switch_holes: choc v1 center pole (Ø3.4) + two stabilizer bosses
    (Ø1.9 at x=±5.5) per key.
    - bottom_tray_cutouts: union of the two -> single DXF to import onto the
    tray floor. Case mounting holes are intentionally excluded (bosses, not
    relief)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
    [config.yaml]
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2026-07-22 case: tighten hotswap cutout to socket silhouette (two-lobe peanut)
    Replaces the bounding-rectangle hotswap relief (case_hotswap_clearance) with
    the actual Kailh Choc socket outline: two overlapping circles over the contact
    cups at the switch pin holes (0,-5.95) and (5,-3.75), unioned into one
    peanut/bowtie loop per key. Cups are hotswap_lobe_radius (2.8) +
    underside_relief_clearance (0.5) = 3.3mm, sized to reach both solder-pad
    centers (x=-3.275 / +8.275) and every B.SilkS corner while overlapping into a
    single loop. Removes the now-unused hotswap_relief_width/height/shift_y units.
    Roughly halves the removed floor area per switch vs the rectangle, so the
    bottom tray keeps more material. Pr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
    [config.yaml]
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2026-07-25 case: stack board perimeter onto keywells for CAD self-centering
    Stack _outer_rect (the board outline, not unioned) onto the keywells
    outline so the exported DXF bbox equals the full board. keywells alone
    is x-symmetric but its y-extent is only the key cluster, so a plain CAD
    import centers it off-board vertically; framing it with the perimeter
    makes it self-center/register on the sketch.
    _outer_rect is moved above keywells because this ergogen version only
    resolves a name: reference to an outline defined earlier in the file.
    [config.yaml]
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
